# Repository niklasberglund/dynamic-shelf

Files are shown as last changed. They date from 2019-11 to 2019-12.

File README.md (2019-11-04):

# Dynamic shelf
Dynamic shelf for laser cutting. Created with OpenSCAD.
You can specify width, depth, height and number of shelves.

Also make sure you modify `materialThickness`, `kerf` and perhaps `fittingOffset`. variables before cutting. The variables set worked well for me with 6mm plywood.

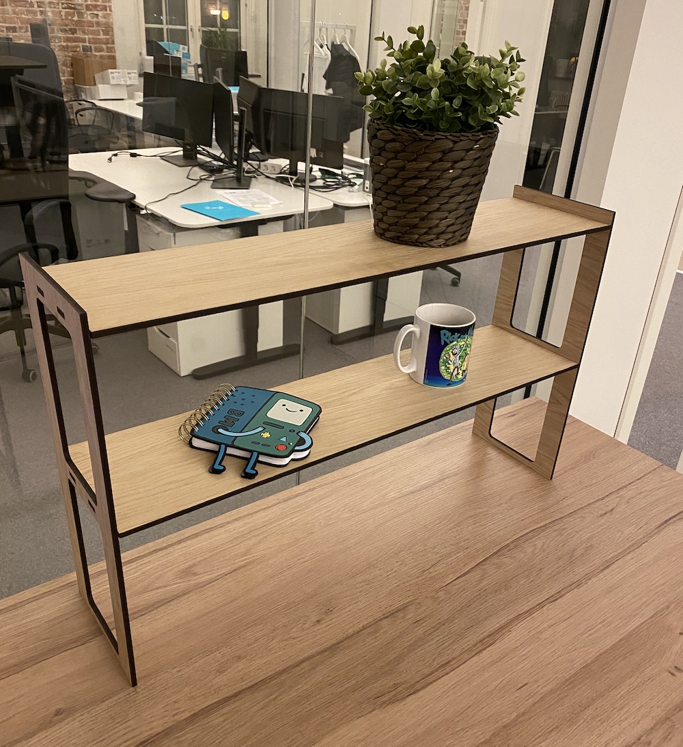
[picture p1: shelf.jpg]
Shelf as cut from example variables Example shelf


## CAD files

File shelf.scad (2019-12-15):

shelfCount = 3;
shelfLength = 540;
depth = 170;
height = 600;
horizontalPillarSize = 35;
verticalPillarSize = 30;
topSpacing = 20;
materialThickness = 6;
stabilizerHeight = 60;
stabilizerFittingPieceWidth = 10;

kerf = 0.2;
fittingOffset = 0.02;
fittingPieceWidth = 20;
spaceBetweenObjects = 20;
holeRoundingRadius = 8;

shelfDepth = depth - materialThickness;

fittingHoleDepth = materialThickness - kerf + (fittingOffset * 2);
fittingHoleLength = fittingPieceWidth - (kerf * 2) + (fittingOffset * 2);
stabilizerFittingHoleDepth = materialThickness - kerf + (fittingOffset * 2);
stabilizerFittingHoleLength = stabilizerFittingPieceWidth - (kerf * 2) + (fittingOffset * 2);

module plotShelf() {
    
    layerHeight = (height - topSpacing) / shelfCount;
    echo("Shelf height(millimeters)", layerHeight);
    
    module plotSide() {
        module plotFittingHoles() {
            for (i = [1:shelfCount]) {
                y = ((height - topSpacing)/(shelfCount)) * i - (fittingHoleDepth/2);
                x1 = (depth/3) * 1 - (fittingHoleLength/2);
                x2 = (depth/3) * 2 - (fittingHoleLength/2);
                
                translate([x1, y]) {
                    square([fittingHoleLength, fittingHoleDepth]);
                }
                
                translate([x2, y]) {
                    square([fittingHoleLength, fittingHoleDepth]);
                }
            }
        }
        
        module plotStabilizerFittingHoles() {
            for (i = [1:shelfCount]) {
                x = depth - stabilizerFittingHoleDepth;
                
                yBase = ((height - topSpacing)/(shelfCount)) * i - (fittingHoleDepth/2);
                y1 = yBase - (stabilizerHeight/3) * 1 - ((stabilizerFittingHoleLength/2));
                y2 = yBase - (stabilizerHeight/3) * 2 - (stabilizerFittingHoleLength/2);
                
                translate([x, y1]) {
                    square([stabilizerFittingHoleDepth, stabilizerFittingHoleLength]);
                }
                
                translate([x, y2]) {
                    square([stabilizerFittingHoleDepth, stabilizerFittingHoleLength]);
                }
                
                //translate([x-20, yBase - stabilizerHeight]) square([stabilizerFittingHoleDepth, stabilizerHeight]);
            }
        }
        
        // Fitting holes for stabilizer against the surface the shelf is standing on
        module plotBottomStabilizerFittingHoles() {
            x = depth - stabilizerFittingHoleDepth;
            
            y1 =  (stabilizerHeight/3) * 1 - (stabilizerFittingHoleLength/2);
            y2 =  (stabilizerHeight/3) * 2 - (stabilizerFittingHoleLength/2);
            
            translate([x, y1]) {
                square([stabilizerFittingHoleDepth, stabilizerFittingHoleLength]);
            }
            
            translate([x, y2]) {
                square([stabilizerFittingHoleDepth, stabilizerFittingHoleLength]);
            }
        }
        
        module plotShelfLevelHoles() {
            for (i = [0:shelfCount-1]) {
                y = i * layerHeight + (verticalPillarSize/2) + (holeRoundingRadius/2);
                
                holeWidth = depth - (horizontalPillarSize * 2) - (holeRoundingRadius * 2);
                holeHeight = layerHeight - verticalPillarSize - (holeRoundingRadius);
                
                translate([horizontalPillarSize + holeRoundingRadius, y]) {
                    minkowski() {
                        square([holeWidth, holeHeight]);
                        circle(r=holeRoundingRadius);
                    }
                }
            }
        }
        
        difference() {
            square([depth, height]);
            
            plotFittingHoles();
            plotStabilizerFittingHoles();
            plotBottomStabilizerFittingHoles();
            plotShelfLevelHoles();
        }
    }
    
    module plotAllLayers() {
        for (i = [0:shelfCount-1]) {
            y = i * (depth + spaceBetweenObjects);
            translate([0, y]) {
                plotLayer();
            }
        }
    }
    
    module plotLayer() {
        module plotLayerFittingPieces() {
            y1 = (depth/3) * 1 - (fittingHoleLength/2);
            y2 = (depth/3) * 2 - (fittingHoleLength/2);
            
            translate([-fittingHoleDepth, y1]) {
                square([fittingHoleDepth, fittingHoleLength]);
            }
            
            translate([-fittingHoleDepth, y2]) {
                square([fittingHoleDepth, fittingHoleLength]);
            }
            
            translate([shelfLength, y1]) {
                square([fittingHoleDepth, fittingHoleLength]);
            }
            
            translate([shelfLength, y2]) {
                square([fittingHoleDepth, fittingHoleLength]);
            }
        }
        
        square([shelfLength, depth]);
        
        plotLayerFittingPieces();
    }
    
    module plotAllStabilizers() {
        for (i = [0:shelfCount]) {
            y = i * (stabilizerHeight + spaceBetweenObjects);
            translate([0, y]) {
                plotStabilizer();
            }
        }
    }
    
    module plotStabilizer() {
        module plotStabilizerFittingPieces() {
            y1 = (stabilizerHeight/3) * 1 - (stabilizerFittingHoleLength/2);
            y2 = (stabilizerHeight/3) * 2 - (stabilizerFittingHoleLength/2);
            
            translate([0, y1]) {
                square([stabilizerFittingHoleDepth, stabilizerFittingHoleLength]);
            }
            
            translate([0, y2]) {
                square([stabilizerFittingHoleDepth, stabilizerFittingHoleLength]);
            }
            
            translate([shelfLength + stabilizerFittingHoleDepth, y1]) {
                square([stabilizerFittingHoleDepth, stabilizerFittingHoleLength]);
            }
            
            translate([shelfLength + stabilizerFittingHoleDepth, y2]) {
                square([stabilizerFittingHoleDepth, stabilizerFittingHoleLength]);
            }
        }
        
        plotStabilizerFittingPieces();
        
        translate([stabilizerFittingHoleDepth, 0]) {
            square([shelfLength, stabilizerHeight]);
        }
    }
    
    // Minimal test pieces for trying out the press fit before laser cutting the whole thing
    module plotFittingTestPieces() {
        module plotFemaleTestPiece() {
            difference() {
                pieceOffset = 10;
                femalePieceWidth = pieceOffset + fittingHoleLength + pieceOffset +  stabilizerFittingHoleDepth + pieceOffset;
                femalePieceHeight = pieceOffset + stabilizerFittingHoleLength + pieceOffset;
                
                square([femalePieceWidth, femalePieceHeight]);
                
                translate([pieceOffset, pieceOffset]) square([fittingHoleLength, fittingHoleDepth]);
                
                stabilizerFittingX = pieceOffset + fittingHoleLength + pieceOffset;
                translate([stabilizerFittingX, pieceOffset]) square([stabilizerFittingHoleDepth, stabilizerFittingHoleLength]);
            }
        }
        
        module plotMaleTestPiece() {
            bottomPieceOffset = 20;
            sidePieceOffset = 10;
            malePieceWidth = bottomPieceOffset + fittingHoleLength + bottomPieceOffset - stabilizerFittingHoleDepth;
            malePieceHeight = sidePieceOffset * 2 + stabilizerFittingHoleLength - fittingHoleDepth;
            
            translate([stabilizerFittingHoleDepth, 0]) {
                square([malePieceWidth, malePieceHeight]);
            }
            
            translate([0, 5]) {
                square([stabilizerFittingHoleDepth, stabilizerFittingHoleLength]);
            }
            
            translate([20, -fittingHoleDepth]) {
                square([fittingHoleLength, fittingHoleDepth]);
            }
        }
        
        plotFemaleTestPiece();
        
        translate([0, 40]) {
            plotMaleTestPiece();
        }
    }
    
    module plotAllShelfPieces() {    
        plotSide();
        
        translate([depth + spaceBetweenObjects, 0]) {
            plotSide();
            
            translate([depth + spaceBetweenObjects, 0]) {
                plotAllLayers();
                
                translate([shelfLength + fittingHoleDepth * 2 + spaceBetweenObjects, 0]) {
                    plotAllStabilizers();
                }
            }
        }
    }
    
    // ### IMPORTANT NOTE ###
    // I'd recommend you to first cut out the test pieces to try out the press fit. 
    // You might have to adjust kerf variable if you're not achieving a good press fit.
    // To do so comment out plotAllShelfPieces() and uncomment plotFittingTestPieces() below
    plotAllShelfPieces();
    //plotFittingTestPieces();
}

plotShelf();

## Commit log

2019-10-27 Basic implementation
    [shelf.scad]
2019-10-27 Plotting big hole in bottom of side
    [shelf.scad]
2019-10-27 Should use fittingHoleLength here
    [shelf.scad]
2019-10-27 Holes in sides implemented
    [shelf.scad]
2019-10-27 Fixed misalignment of holes in side
    [shelf.scad]
2019-10-27 Fix for plotting one shelf too many
    [shelf.scad]
2019-11-04 Removed bottom hole in sides
    [shelf.scad]
2019-11-04 Echo:ing height
    [shelf.scad]
2019-11-04 Corrected kerf
    [shelf.scad]
2019-11-04 Changed fitting offset to what worked well when I cut it out
    [shelf.scad]
2019-11-04 Side holes all the way to the bottom
    [shelf.scad]
2019-11-04 Updated dimensions in example
    To match my cut
    [shelf.scad]
2019-11-04 README with photo of example cut out
2019-12-09 Added stabilizers
    [shelf.scad]
2019-12-09 Fix for shelf fitting pieces not updated
    [shelf.scad]
2019-12-09 Shelf fitting holes centered in side for symmetrical beauty
    [shelf.scad]
2019-12-12 Stabilizers under shelf instead of behind
    [shelf.scad]
2019-12-12 Added another stabilizer against surface the shelf is standing on
    [shelf.scad]
2019-12-15 Corrected stabilizer fitting holes position
    [shelf.scad]
2019-12-15 Updated default parameters
    [shelf.scad]
2019-12-15 Added test pieces
    [shelf.scad]
